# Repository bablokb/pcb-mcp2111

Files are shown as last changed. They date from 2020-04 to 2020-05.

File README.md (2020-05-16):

A small pcb for the MCP2221 chip
================================

The MCP2221 chip is an USB to GPIO bridge and brings GPIOs (including I2C) to any computer.

This github-repository contains a Kicad-project for the chip:

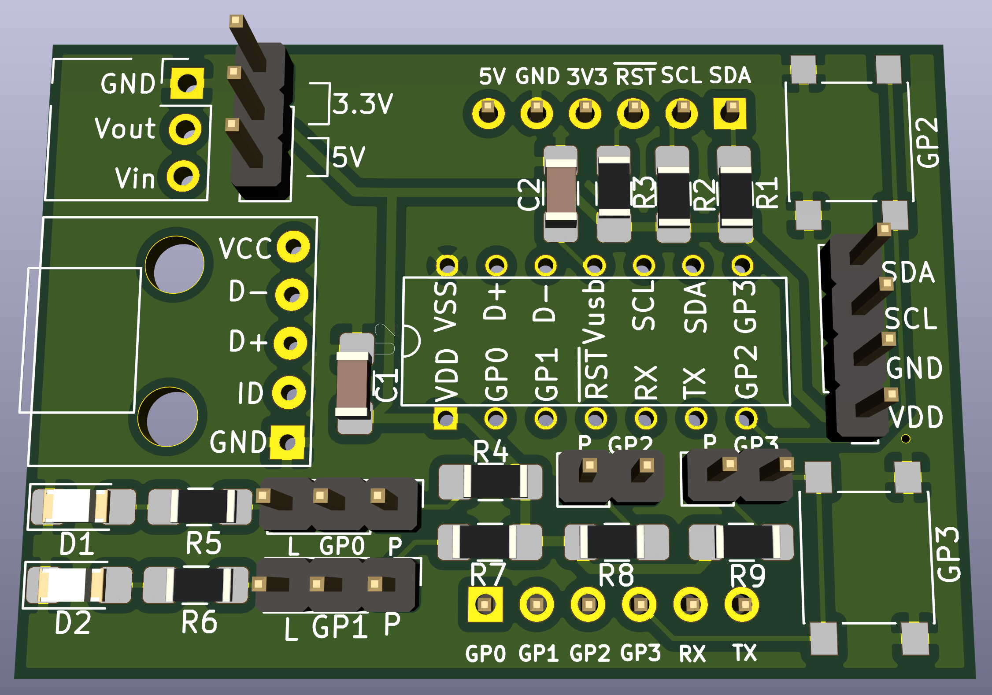
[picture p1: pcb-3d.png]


Status
------

Current status: the pcb was successfully produced
by [https://aisler.net](https://aisler.net):

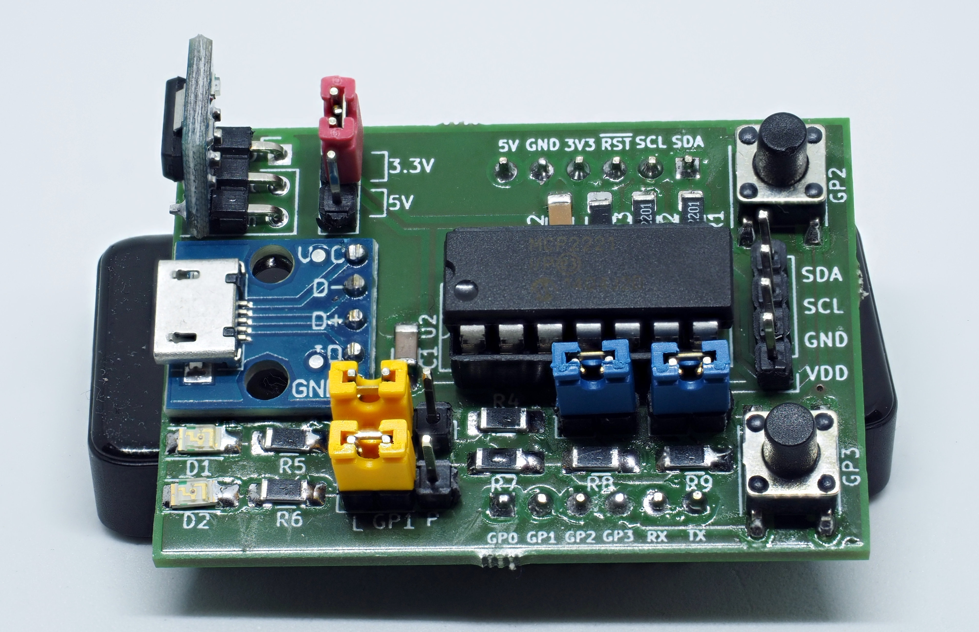
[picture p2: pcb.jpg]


Hardware
--------

Components for the board:

  - MCP2221/MCP2221A
  - socket
  - two capacitors (required, see datasheet)
  - a micro-sd-female connector (breakout)
  - an AMS1117 5V->3.3V converter (breakout, configurable using jumper-shim)
  - pullups for I2C-pins
  - pullups for GP0-GP3 (configurable using jumper-shims)
  - LEDs for GP0 and GP1 (configurable using jumper-shims)
  - buttons for GP2 and GP3
  - two male-connectors exposing all pins of the MCP2221 (breadboard-friendly spacing)

You can find details in the file `part-list.ods`.

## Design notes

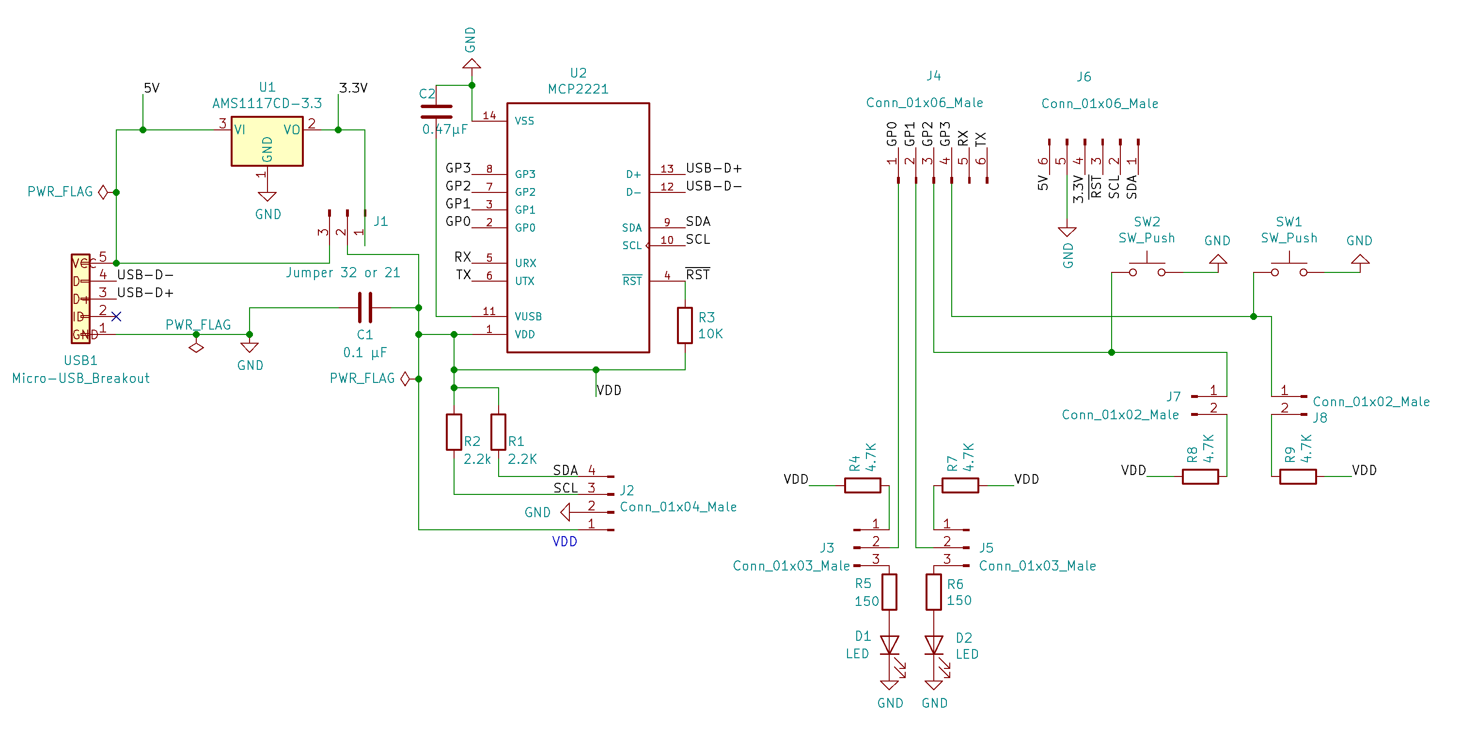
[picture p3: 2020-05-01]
schematic.png

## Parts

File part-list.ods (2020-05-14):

Ref | Qnty | Value | Footprint
C1 | 1 | 0.1 µF | SMD 1206
C2 | 1 | 0.47µF | SMD 1206
D1, D2 | 2 | LED | SMD 1206
J1 | 1 | Conn_01x03_Male | 3x1 Pin-Header 2.54
J2 | 1 | Conn_01x04_Male | 4x1 Pin-Header 2.54
J3, J5 | 2 | Conn_01x03_Male | 3x1 Pin-Header 2,54
J4, J6 | 2 | Conn_01x06_Male | 6x1 Pin-Header 2.54
J7, J8 | 2 | Conn_01x02_Male | 2x1 Pin-Header 2.54
R1, R2 | 2 | 2.2KΩ | SMD 1206
R3 | 1 | 10KΩ | SMD 1206
R4, R7, R8, R9 | 4 | 4.7KΩ | SMD 1206
R5, R6 | 2 | 150Ω | SMD 1206
SW1, SW2 | 2 | SW_Push | SMD Push-Button
U1 | 1 | AMS1117CD-3.3 | AMS1117-Breakout
U2 | 1 | MCP2221 | IC Sockel 2x7
USB1 | 1 | Micro-USB_Breakout | Micro-USB-Breakout

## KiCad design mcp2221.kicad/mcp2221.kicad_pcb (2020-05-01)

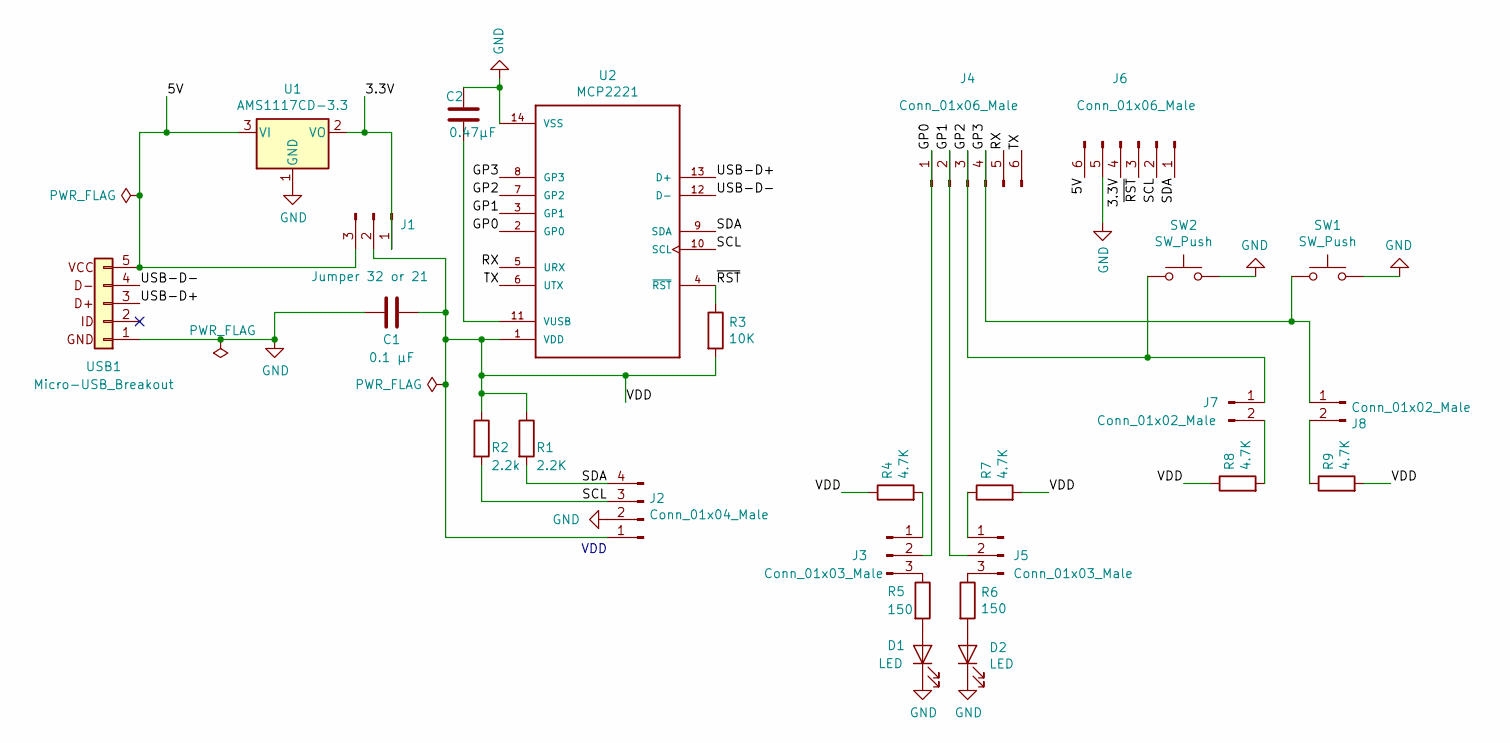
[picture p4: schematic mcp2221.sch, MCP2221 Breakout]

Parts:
C1: 0.1 µF; C_1206_3216_Pad1.7x1.75mm_BB
C2: 0.47µF; C_1206_3216_Pad1.7x1.75mm_BB
D1, D2: LED; LED_1206_3216_Pad1.7x1.75mm_BB
J1: Jumper 32 or 21; PinHeader_1x03_P2.54mm_Vertical
J2: Conn_01x04_Male; PinHeader_1x04_P2.54mm_Vertical
J3, J5: Conn_01x03_Male; PinHeader_1x03_P2.54mm_Vertical
J4, J6: Conn_01x06_Male; PinHeader_1x06_P2.54mm_Vertical
J7, J8: Conn_01x02_Male; PinHeader_1x02_P2.54mm_Vertical
R1: 2.2K; R_1206_3216_Pad1.7x1.75mm_BB
R2: 2.2k; R_1206_3216_Pad1.7x1.75mm_BB
R3: 10K; R_1206_3216_Pad1.7x1.75mm_BB
R4, R7, R8, R9: 4.7K; R_1206_3216_Pad1.7x1.75mm_BB
R5, R6: 150; R_1206_3216_Pad1.7x1.75mm_BB
SW1, SW2: SW_Push; SW_Push_1P1T_NO_6x6mm_H9.5mm
U1: AMS1117CD-3.3; AMS1117_Breakout
U2: MCP2221
USB1: Micro-USB_Breakout

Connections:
/3.3V: J1.1, J6.4, U1.2 (VO)
/5V: J1.3, J6.6, U1.3 (VI), USB1.5
/GP0: J3.2, J4.1, U2.2 (GP0)
/GP1: J4.2, J5.2, U2.3 (GP1)
/GP2: J4.3, J7.1, SW2.1, U2.7 (GP2)
/GP3: J4.4, J8.1, SW1.1, U2.8 (GP3)
/RX: J4.5, U2.5 (URX)
/SCL: J2.3, J6.2, R2.2, U2.10 (SCL)
/SDA: J2.4, J6.1, R1.2, U2.9 (SDA)
/TX: J4.6, U2.6 (UTX)
/USB-D+: U2.13 (D+), USB1.3
/USB-D-: U2.12 (D-), USB1.4
/VDD: C1.1, J1.2, J2.1, R1.1, R2.1, R3.2, R4.1, R7.2, R8.1, R9.2, U2.1 (VDD)
/~RST~: J6.3, R3.1, U2.4 (~RST~)
GND: C1.2, C2.2, D1.1 (K), D2.1 (K), J2.2, J6.5, SW1.2, SW2.2, U1.1 (GND), U2.14 (VSS), USB1.1
unnamed: C2.1, U2.11 (VUSB)
unnamed: D1.2 (A), R5.2
unnamed: D2.2 (A), R6.2
unnamed: J3.1, R4.2
unnamed: J3.3, R5.1
unnamed: J5.1, R7.1
unnamed: J5.3, R6.1
unnamed: J7.2, R8.2
unnamed: J8.2, R9.1

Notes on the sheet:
VDD

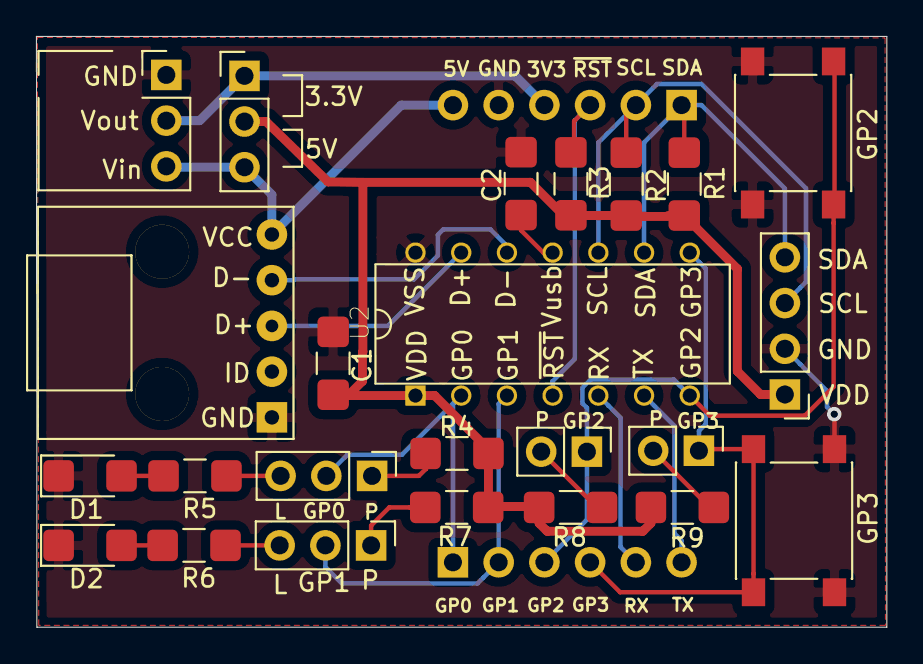
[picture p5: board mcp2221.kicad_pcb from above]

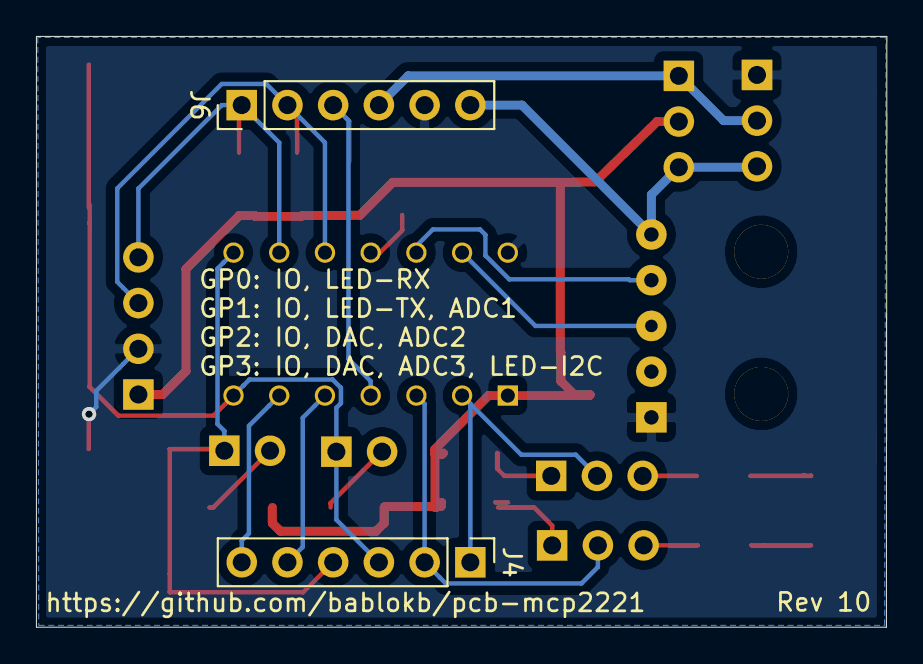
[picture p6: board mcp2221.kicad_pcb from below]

Board: 2 copper layers, 47.2 x 32.8 mm, 26 parts (2 on the bottom side), 24 nets.

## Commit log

2020-03-06 update link to github-repository
    [mcp2221.sch]
2020-03-10 replaced 4-pin USB-connector with 5-pin connector
    [mcp2221.sch]
2020-03-11 Rev 4: added pullups for all GPs, added SW1 to GP3
    [mcp2221.sch]
2020-03-24 added footprints, created initial pcb
    [mcp2221.kicad_pcb, mcp2221.sch]
2020-04-05 pcb layout changes
    [mcp2221.kicad_pcb]
2020-04-09 Rev 6: switched to SMD, added connector, minor tweaks
    [mcp2221.sch]
2020-04-09 initial layout for SMD
    [mcp2221.kicad_pcb]
2020-04-10 added text on F.Silks
    [mcp2221.kicad_pcb]
2020-04-11 updated footprint of AMS1117
    [mcp2221.kicad_pcb]
2020-04-11 changed track width of power-tracks
    [mcp2221.kicad_pcb]
2020-04-11 moved C2 and R1-R3 to MCP2221
    [mcp2221.kicad_pcb]
2020-04-11 added labels
    [mcp2221.kicad_pcb]
2020-04-11 fine-tuned labels
    [mcp2221.kicad_pcb]
2020-04-14 make distance between connectors a multiple of 2.54 / optimize layout
    [mcp2221.kicad_pcb]
2020-04-14 Rev 7: added button for GP2
    [mcp2221.kicad_pcb, mcp2221.sch]
2020-04-14 optimized labels
    [mcp2221.kicad_pcb]
2020-04-17 changed to larger pads on SMD-footprints
    [mcp2221.kicad_pcb, mcp2221.sch]
2020-04-17 changed I2C-connector
    [mcp2221.kicad_pcb, mcp2221.sch]
2020-04-18 changed revision-number to 8
    [mcp2221.kicad_pcb, mcp2221.sch]
2020-04-18 updated to reflect current version
2020-04-18 optimzed labels
    [mcp2221.kicad_pcb]
2020-04-18 added description of GPs on back of pcb
    [mcp2221.kicad_pcb]
2020-04-30 Rev 9: don't connect Vusb to 3.3V / changed R for LEDs to 150
    [mcp2221.kicad_pcb, mcp2221.sch]
2020-04-30 fixed labels
    [mcp2221.kicad_pcb]
2020-05-01 Rev 10: fix order of D-/D+ in schematic+pcb
    [mcp2221.kicad_pcb, mcp2221.sch]
